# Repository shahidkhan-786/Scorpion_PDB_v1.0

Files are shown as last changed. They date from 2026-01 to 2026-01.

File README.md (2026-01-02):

# Scorpion_PDB_v1.0

I am making a Buck converter. 
I am making it using a TPS563200 Chip...I used ths because it is Small, Cheap, and Reliable to output 3A Current.



This is my schematic...I mostly referred to DataSheet of TPS563200.



This is the Layout/Routing part...I think this was the hardest part of the project, since the DataSheet gave very strict instructions for this.



Hopefully after soldering all components it look like this.

The sole purpose of the project is to power my Drone...or Future Drone : "Scorpion" ;)

Note : PDB translates to 'Power Distribution Board'

As the name suggests it will disribute power to all my Servo motors, ESC's, ESP32 (which i will be using for my Flight Controller for Scorpion) and/or any other Sensors
that I will be using in future...that's exactly why I have created 7 outputs...!

Here is the BOM of this PDB : 



This is Component Part.



This is PCB Part (I am ordering from JLCPCB).

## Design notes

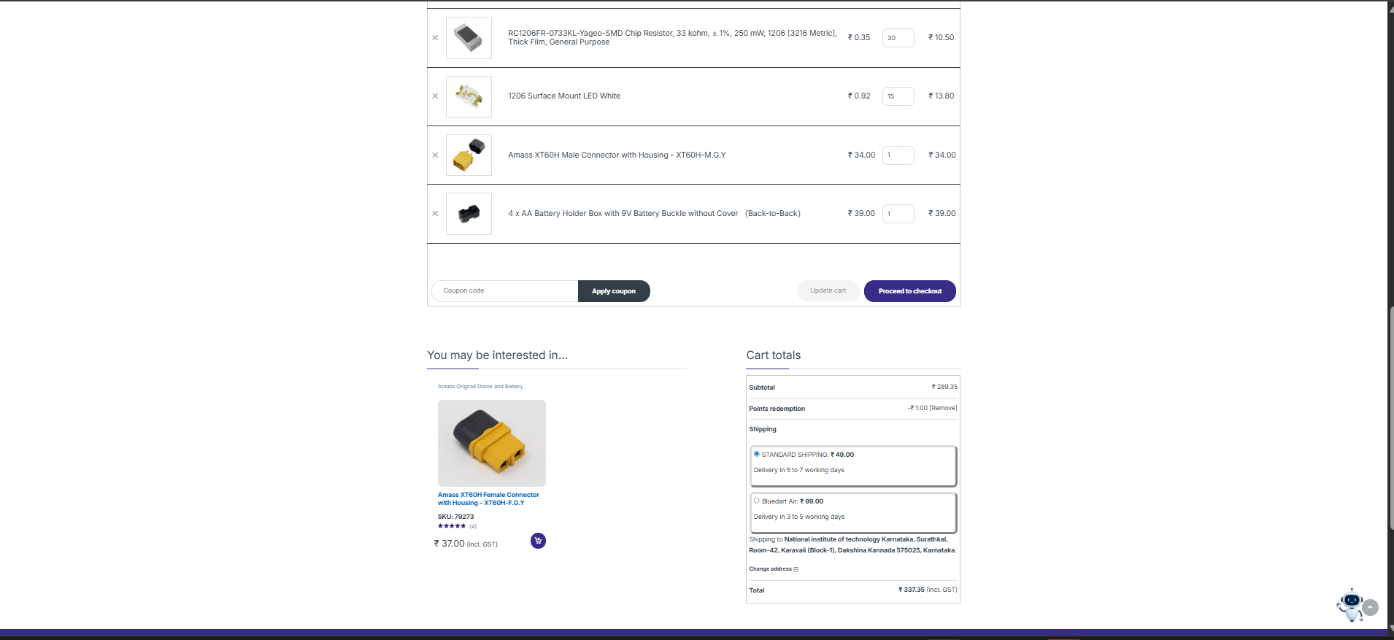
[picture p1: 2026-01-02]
Screenshot 2026-01-03 020707.png

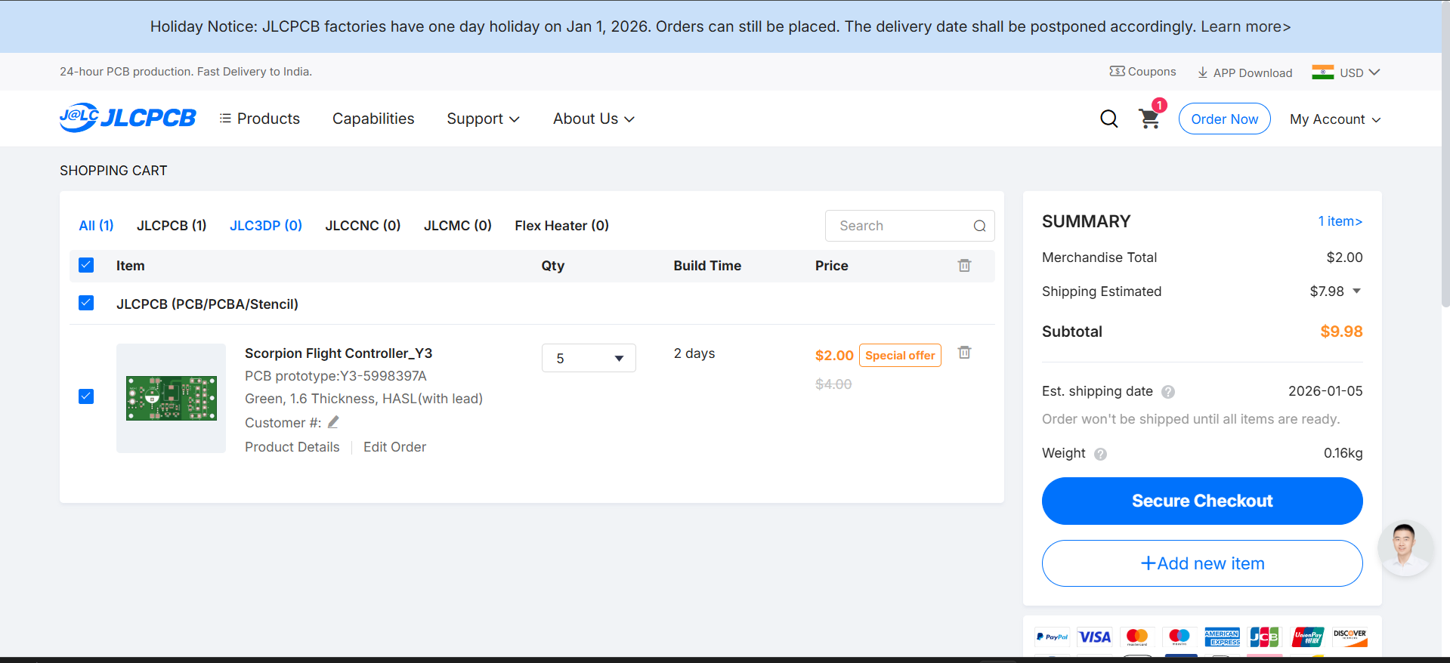
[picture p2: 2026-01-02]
Screenshot 2026-01-03 020340.png

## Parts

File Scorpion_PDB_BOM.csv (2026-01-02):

Item | Description | Quantity | Unit Price (₹) | Total Price (₹) | URL | Running Total (₹)
TPS563200 | Buck Chip | 2 | 20 | 40 | TPS563200DDCR-Texas Instruments-Step-down type Adjustable 760mV~7V 3A 4.5V~17V TSOT-23-6 DC-DC Converters ROHS | 40
4.7uH Inductor | Inductor | 2 | 15 | 30 | CDRH104R 4.7uH Power Inductor | 70
10uF Capacitor | Capacitor | 5 | 7 | 35 | CL31B106KBHNNNE-Samsung-50V 10uF X7R ±10% 1206 Multilayer Ceramic Capacitors MLCC - SMD/SMT ROHS | 105
22uF Capacitor | Capacitor | 5 | 2.85 | 14.25 | CL31A226KOHNNNE-Samsung-16V 22uF X5R ±10% 1206 Multilayer Ceramic Capacitors MLCC - SMD/SMT ROHS | 119.25
100nF Capacitor | Capacitor | 15 | 0.72 | 10.8 | CL21B104KBCNFNC-Samsung-50V 100nF X7R ±10% 0805 Multilayer Ceramic Capacitors MLCC - SMD/SMT ROHS | 130.05
1000uF Capacitor | Capacitor | 2 | 15 | 30 | 25YXJ1000MT810X20-Rubycon-1000uF 25V 46mΩ@100kHz ±20% 1.4A@100kHz Plugin,D10xL20mm Aluminum Electrolytic Capacitors - Leaded ROHS | 160.05
56k ohm Resistor | Resistor | 30 | 0.35 | 10.5 | RC1206FR-0756KL-Yageo-SMD Chip Resistor, 56 kohm, ± 1%, 250 mW, 1206 [3216 Metric], Thick Film, General Purpose | 170.55
1k ohm Resistor | Resistor | 25 | 0.46 | 11.5 | RC1206FR-071KL-YAGEO-Res Thick Film 1206 1K Ohm 1% 0.25W(1/4W) ±100ppm/°C Pad SMD T/R | 182.05
33k ohm Resistor | Resistor | 30 | 0.35 | 10.5 | RC1206FR-0733KL-Yageo-SMD Chip Resistor, 33 kohm, ± 1%, 250 mW, 1206 [3216 Metric], Thick Film, General Purpose | 192.55
10k ohm Resistor | Resistor | 40 | 0.25 | 10 | RC1206FR-0710KL-YAGEO-Res Thick Film 1206 10K Ohm 1% 0.25W(1/4W) ±100ppm/°C Pad SMD T/R | 202.55
LED | LED | 15 | 0.92 | 13.8 | 1206 Surface Mount LED White | 216.35
XT-60 | Connector | 1 | 34 | 34 | Amass XT60H Male Connector with Housing - XT60H-M.G.Y | 250.35
Holder | Battery Holder | 1 | 39 | 39 | 4 x AA Battery Holder Box with 9V Battery Buckle without Cover （Back-to-Back） | 289.35
Shipping | of Components | _ | _ | 49 | _ | 338.35
Discount | _ | _ | _ | 1 | _ | 337.35
Item | Quantity | Price ($) | Running Total ($)
PCB | 5 | 2 | 2
Shipping | _ | 7.98 | 9.98

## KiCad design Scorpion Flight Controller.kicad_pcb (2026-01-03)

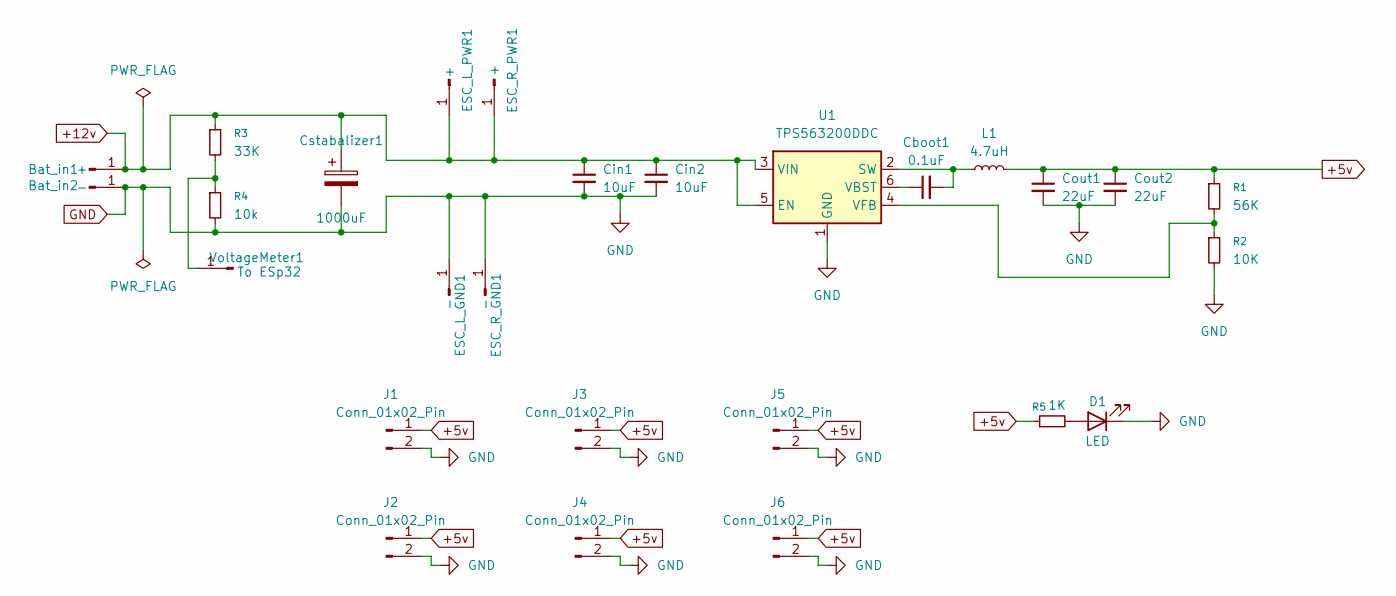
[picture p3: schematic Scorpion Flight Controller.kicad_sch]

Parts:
Bat_in1: +; TestPoint_Plated_Hole_D3.0mm
Bat_in2: -; TestPoint_Plated_Hole_D3.0mm
Cboot1: 0.1uF; C_0805_2012Metric_Pad1.18x1.45mm_HandSolder
Cin1, Cin2: 10uF; C_1206_3216Metric_Pad1.33x1.80mm_HandSolder
Cout1, Cout2: 22uF; C_1206_3216Metric_Pad1.33x1.80mm_HandSolder
Cstabalizer1: 1000uF; CP_Radial_D10.0mm_P5.00mm
D1: LED; LED_1206_3216Metric_Pad1.42x1.75mm_HandSolder
ESC_L_GND1: -; TestPoint_Pad_2.5x2.5mm
ESC_L_PWR1: +; TestPoint_Pad_2.5x2.5mm
ESC_R_GND1: -; TestPoint_Pad_2.5x2.5mm
ESC_R_PWR1: +; TestPoint_Pad_2.5x2.5mm
J1, J2, J3, J4, J5, J6: Conn_01x02_Pin; TestPoint_2Pads_Pitch5.08mm_Drill1.3mm
L1: 4.7uH; L_10.4x10.4_H4.8
R1: 56K; R_1206_3216Metric_Pad1.30x1.75mm_HandSolder
R2: 10K; R_1206_3216Metric_Pad1.30x1.75mm_HandSolder
R3: 33K; R_1206_3216Metric_Pad1.30x1.75mm_HandSolder
R4: 10k; R_1206_3216Metric_Pad1.30x1.75mm_HandSolder
R5: 1K; R_1206_3216Metric_Pad1.30x1.75mm_HandSolder
U1: TPS563200DDC; SOT-23-6
VoltageMeter1: To ESp32; TestPoint_THTPad_1.0x1.0mm_Drill0.5mm

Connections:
+5v: Cout1.1, Cout2.1, J1.1, J2.1, J3.1, J4.1, J5.1, J6.1, L1.2, R1.1, R5.1; also elsewhere on the board
+12v: Bat_in1.1, Cin1.1, Cin2.1, Cstabalizer1.1, ESC_L_PWR1.1, ESC_R_PWR1.1, R3.1, U1.3 (VIN), U1.5 (EN)
GND: Bat_in2.1, Cin1.2, Cin2.2, Cout1.2, Cout2.2, Cstabalizer1.2, D1.1 (K), ESC_L_GND1.1, ESC_R_GND1.1, J1.2, J2.2, J3.2, J4.2, J5.2, J6.2, R2.2, R4.2, U1.1 (GND); also elsewhere on the board
unnamed: D1.2 (A), R5.2
unnamed: Cboot1.2, L1.1, U1.2 (SW)
unnamed: Cboot1.1, U1.6 (VBST)
unnamed: R1.2, R2.1, U1.4 (VFB)
unnamed: R3.2, R4.1, VoltageMeter1.1

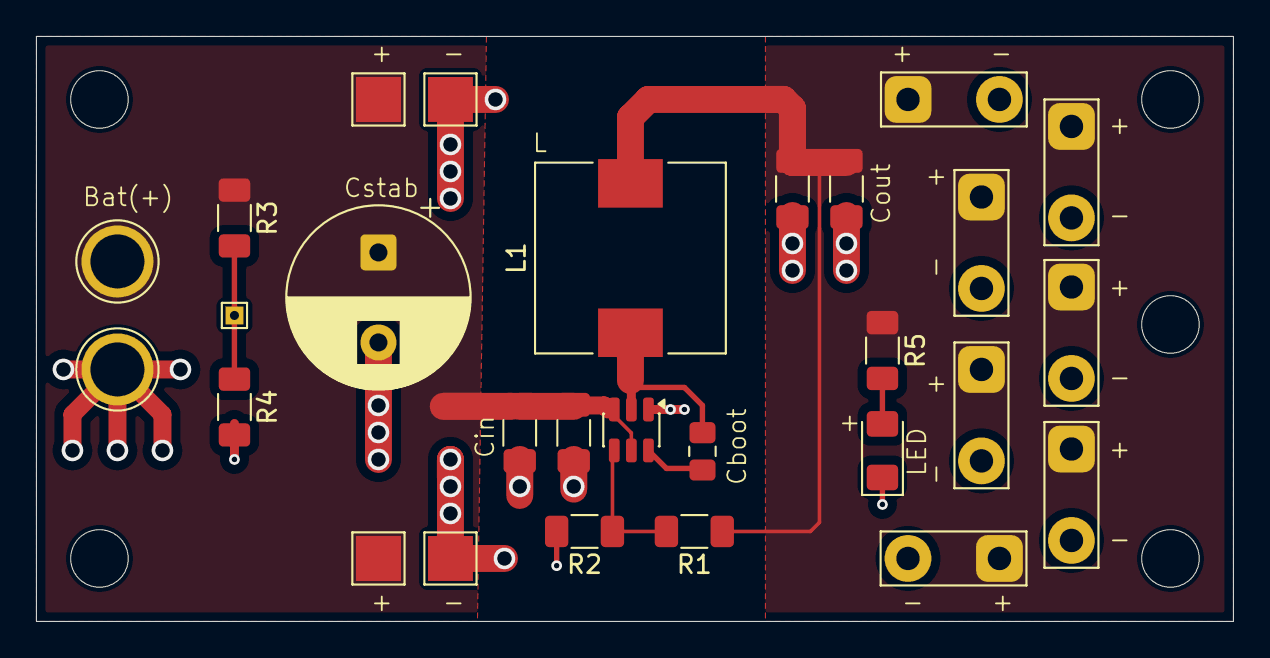
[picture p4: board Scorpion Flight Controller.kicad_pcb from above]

Board: 2 copper layers, 66.5 x 32.5 mm, 28 parts (0 on the bottom side), 8 nets.

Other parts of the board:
J7: Conn_01x02_Pin; TestPoint_2Pads_Pitch5.08mm_Drill1.3mm

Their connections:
+5v: J7.1; also elsewhere on the board
GND: J7.2; also elsewhere on the board

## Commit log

2026-01-02 Project Description
    Expanded project description and added images for schematic, layout, BOM, and components.
2026-01-02 This is BOM
    I have added both Components and PCB in this single file.
    [Scorpion_PDB_BOM.csv]
2026-01-03 Kicad Source files.
    [Scorpion Flight Controller.kicad_pcb, Scorpion Flight Controller.kicad_sch]
